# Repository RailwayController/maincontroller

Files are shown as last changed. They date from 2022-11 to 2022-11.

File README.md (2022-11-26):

<!--
SPDX-FileCopyrightText: 2022 Sidings Media <contact@sidingsmedia.com>
SPDX-License-Identifier: CC-BY-SA-4.0
-->

# Railway Controller - Main control board

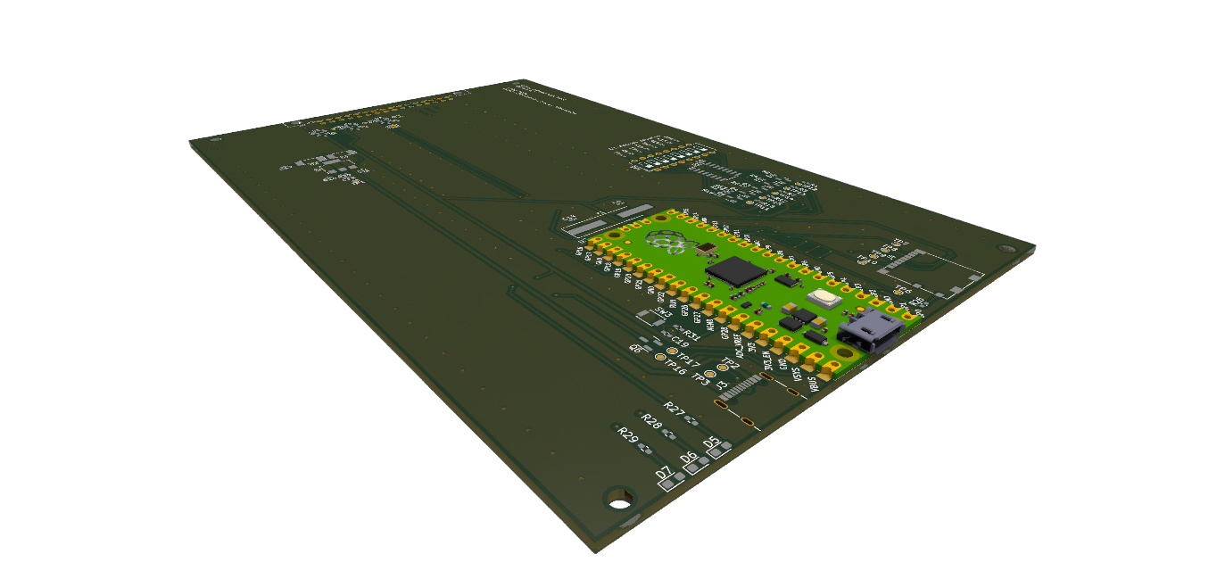
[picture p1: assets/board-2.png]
Render of main control board


The main control board is the central control node of the railway controller
system. The main control board controls all aspects of the system, from handling
user inputs to sending commands to the control nodes.

The board is based upon the RP2040 and can either be fitted with a Raspberry Pi
Pico board or use the RP2040 chip on it's own with all the required supporting
circuitry being implemented on the board it's self. The board is designed to fit
inside a standard 3U eurocard enclosure with a depth of 160mm and a height of
100mm. The rear connector provides connectivity to the backplane to allow
communication between all nodes in the rack as well as to supply power to the
board.

The PCBs have been designed with 2 layers and with SMD components that should be
possible to hand solder with a small tip and some practice. An important note,
the boards have been designed acording to JLCPCB's design constraints, if you
are ordering from a different manufacturer, it is a good idea to make sure that
they support the same or better constraints.

This repository contains designs for the main controller board for
use with the railway controller system. Rendered versions of the schematics, for
example schematics in the PDF format, are included with the releases. Gerber
files are also included with releases. These have been generated to work with
JLCPCB but they should work with most other board manufacturers. 

## Licence
This repo uses the [REUSE](https://reuse.software) standard in order to
communicate the correct licence for the file. For those unfamiliar with
the standard the licence for each file can be found in one of three
places. The licence will either be in a comment block at the top of the
file, in a `.license` file with the same name as the file, or in the
dep5 file located in the `.reuse` directory. If you are unsure of the
licencing terms please contact
[contact@sidingsmedia.com](mailto:contact@sidingsmedia.com?subject=Railway%20Controller%20Licence).
All files committed to this repo must contain valid licencing
information or the pull request can not be accepted.

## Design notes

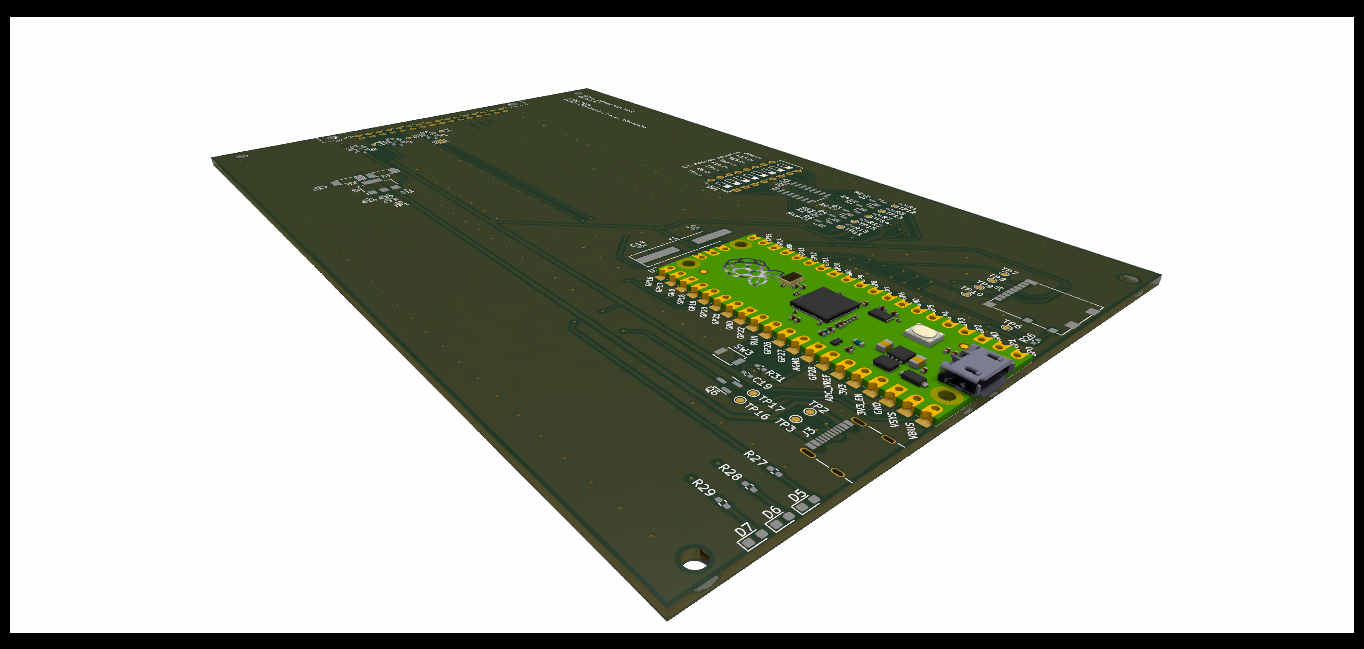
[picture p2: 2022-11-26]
assets/board-1.png

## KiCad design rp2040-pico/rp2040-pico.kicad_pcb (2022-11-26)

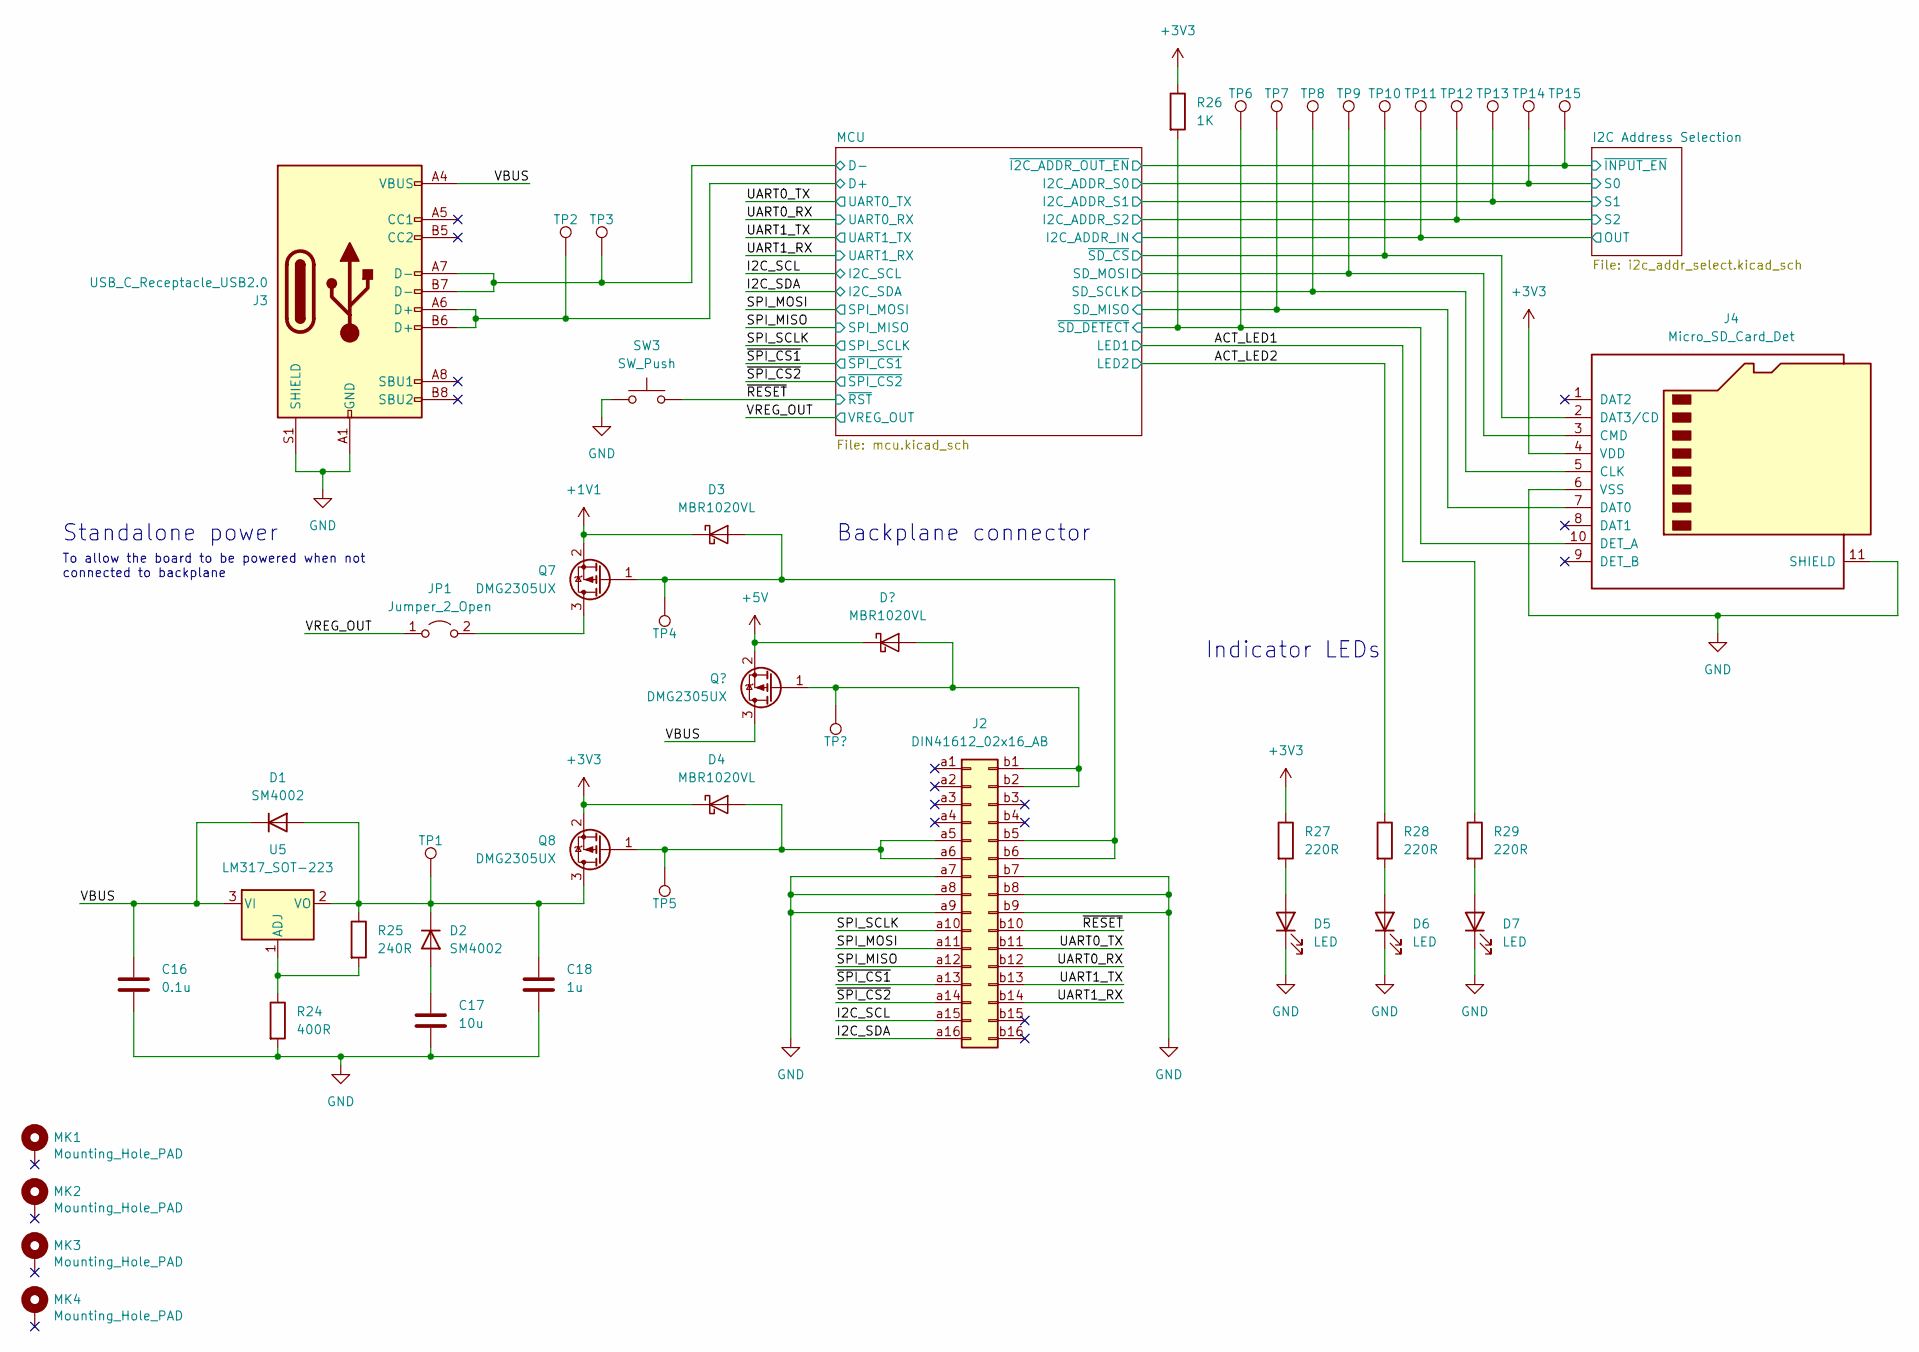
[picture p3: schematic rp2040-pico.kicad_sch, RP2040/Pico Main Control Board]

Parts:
C16: 0.1u; C_0402_1005Metric_Pad0.74x0.62mm_HandSolder
C17: 10u; C_0402_1005Metric_Pad0.74x0.62mm_HandSolder
C18: 1u; C_0402_1005Metric_Pad0.74x0.62mm_HandSolder
D1, D2: SM4002; D_MELF
D3, D4: MBR1020VL; D_SOD-123F
D5, D6, D7: LED; LED_0603_1608Metric_Pad1.05x0.95mm_HandSolder
J2: DIN41612_02x16_AB; DIN41612_B2_2x16_Male_Horizontal_THT
J3: USB_C_Receptacle_USB2.0; USB_C_Receptacle_Palconn_UTC16-G
J4: Micro_SD_Card_Det; microSD_HC_Molex_104031-0811
JP1: Jumper_2_Open; SolderJumper-2_P1.3mm_Open_Pad1.0x1.5mm
MK1, MK2, MK3, MK4: Mounting_Hole_PAD; MountingHole_2.7mm
Q7, Q8: DMG2305UX; SOT-23
R24: 400R; R_0402_1005Metric_Pad0.72x0.64mm_HandSolder
R25: 240R; R_0402_1005Metric_Pad0.72x0.64mm_HandSolder
R26: 1K; R_0402_1005Metric_Pad0.72x0.64mm_HandSolder
R27, R28, R29: 220R; R_0402_1005Metric_Pad0.72x0.64mm_HandSolder
SW3: SW_Push; SW_SPST_B3U-1000P
TP1, TP2, TP3, TP4, TP5, TP6, TP7, TP8, TP9, TP10, TP11, TP12, TP13, TP14, TP15: TestPoint; TestPoint_Pad_D1.0mm
U5: LM317_SOT-223; SOT-223-3_TabPin2

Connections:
+1V1: D3.1 (K), Q7.2 (S); also elsewhere on the board
+3V3: D4.1 (K), J4.4 (VDD), Q8.2 (S), R26.1, R27.1; also elsewhere on the board
/ACT_LED1: R29.1; also elsewhere on the board
/ACT_LED2: R28.1; also elsewhere on the board
/I2C Address Selection/OUT: TP11.1; also elsewhere on the board
/I2C Address Selection/S0: TP14.1; also elsewhere on the board
/I2C Address Selection/S1: TP13.1; also elsewhere on the board
/I2C Address Selection/S2: TP12.1; also elsewhere on the board
/I2C Address Selection/~INPUT_EN: TP15.1; also elsewhere on the board
/I2C_SCL: J2.a15; also elsewhere on the board
/I2C_SDA: J2.a16; also elsewhere on the board
/MCU/D+: J3.A6 (D+), J3.B6 (D+), TP2.1; also elsewhere on the board
/MCU/D-: J3.A7 (D-), J3.B7 (D-), TP3.1; also elsewhere on the board
/MCU/SD_MISO: J4.7 (DAT0), TP7.1; also elsewhere on the board
/MCU/SD_MOSI: J4.3 (CMD), TP9.1; also elsewhere on the board
/MCU/SD_SCLK: J4.5 (CLK), TP8.1; also elsewhere on the board
/MCU/~SD_CS: J4.2 (DAT3/CD), TP10.1; also elsewhere on the board
/MCU/~SD_DETECT: J4.10 (DET_A), R26.2, TP6.1; also elsewhere on the board
/SPI_MISO: J2.a12; also elsewhere on the board
/SPI_MOSI: J2.a11; also elsewhere on the board
/SPI_SCLK: J2.a10; also elsewhere on the board
/UART0_RX: J2.b12; also elsewhere on the board
/UART0_TX: J2.b11; also elsewhere on the board
/UART1_RX: J2.b14; also elsewhere on the board
/UART1_TX: J2.b13; also elsewhere on the board
/VBUS: C16.1, D1.1 (K), J3.A4 (VBUS), J3.A9 (VBUS), J3.B4 (VBUS), J3.B9 (VBUS), U5.3 (VI); also elsewhere on the board
/VREG_OUT: JP1.1 (A); also elsewhere on the board
/~RESET: J2.b10, SW3.2; also elsewhere on the board
/~SPI_CS1: J2.a13; also elsewhere on the board
/~SPI_CS2: J2.a14; also elsewhere on the board
GND: C16.2, C17.2, C18.2, D5.1 (K), D6.1 (K), D7.1 (K), J2.a7, J2.a8, J2.a9, J2.b7, J2.b8, J2.b9, J3.A1 (GND), J3.A12 (GND), J3.B1 (GND), J3.B12 (GND), J3.S1 (SHIELD), J4.6 (VSS), J4.11 (SHIELD), R24.2, SW3.1; also elsewhere on the board
unnamed: C17.1, D2.2 (A)
unnamed: C18.1, D1.2 (A), D2.1 (K), Q8.3 (D), R25.1, TP1.1, U5.2 (VO)
unnamed: D3.2 (A), J2.b5, J2.b6, Q7.1 (G), TP4.1
unnamed: D4.2 (A), J2.a5, J2.a6, Q8.1 (G), TP5.1
unnamed: D5.2 (A), R27.2
unnamed: D6.2 (A), R28.2
unnamed: D7.2 (A), R29.2
unnamed 51: J2.b1, J2.b2; also elsewhere on the board
unnamed: JP1.2 (B), Q7.3 (D)
unnamed: R24.1, R25.2, U5.1 (ADJ)

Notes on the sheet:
To allow the board to be powered when not connected to backplane
Backplane connector
Standalone power
Indicator LEDs

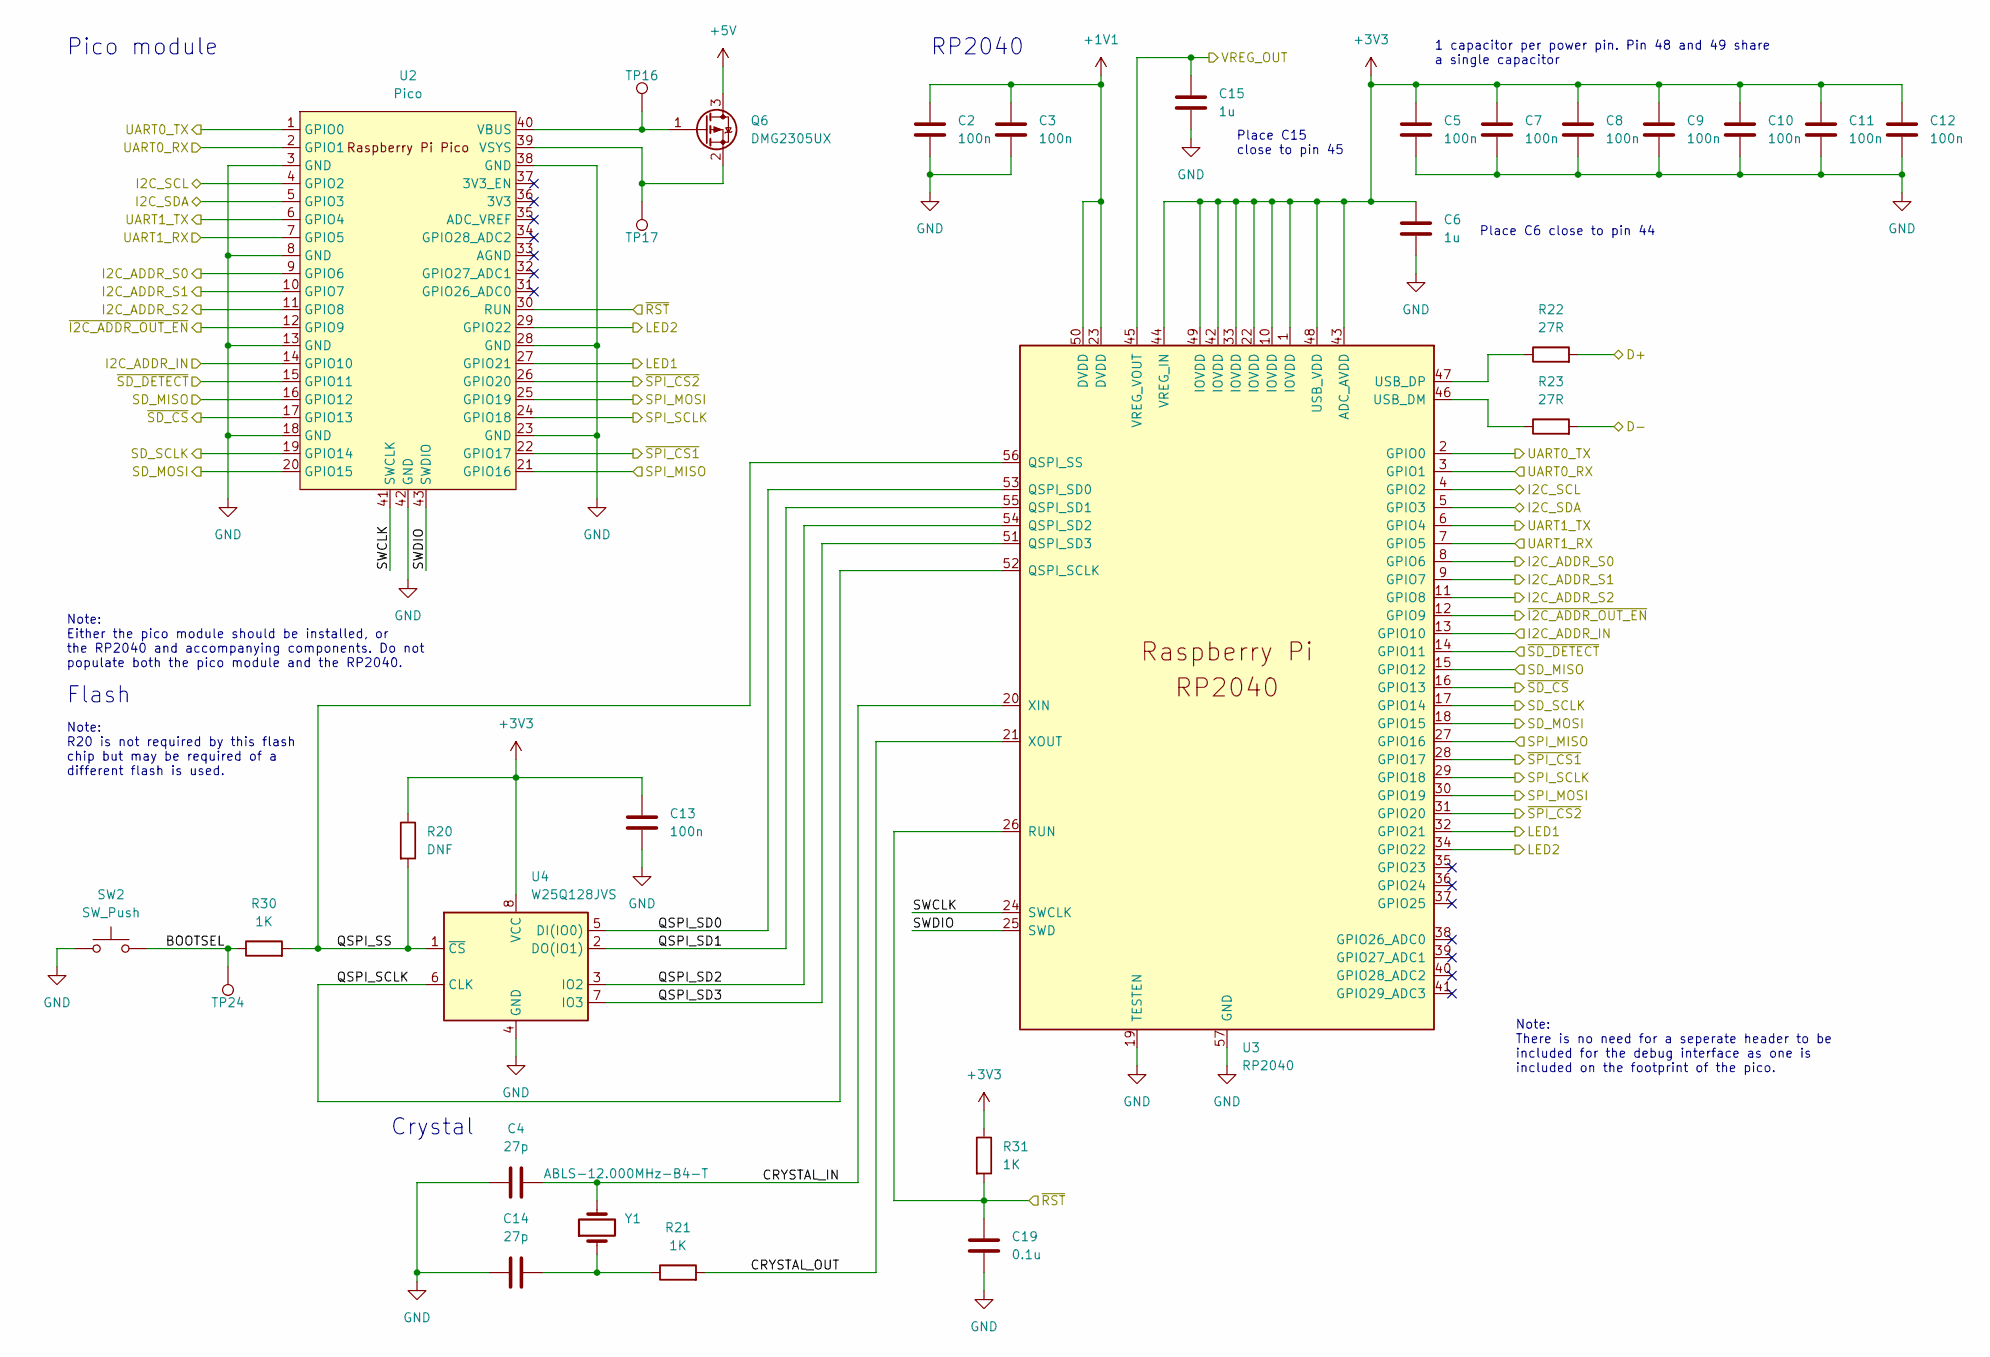
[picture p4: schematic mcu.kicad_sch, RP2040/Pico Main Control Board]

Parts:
C2, C3, C5, C7, C8, C9, C10, C11, C12, C13: 100n; C_0402_1005Metric_Pad0.74x0.62mm_HandSolder
C4, C14: 27p; C_0402_1005Metric_Pad0.74x0.62mm_HandSolder
C6, C15: 1u; C_0402_1005Metric_Pad0.74x0.62mm_HandSolder
C19: 0.1u; C_0402_1005Metric_Pad0.74x0.62mm_HandSolder
Q6: DMG2305UX; SOT-23
R20: DNF; R_0402_1005Metric_Pad0.72x0.64mm_HandSolder
R21, R30, R31: 1K; R_0402_1005Metric_Pad0.72x0.64mm_HandSolder
R22, R23: 27R; R_0402_1005Metric_Pad0.72x0.64mm_HandSolder
SW2: SW_Push; SW_SPST_B3U-1000P
TP16, TP17, TP24: TestPoint; TestPoint_Pad_D1.0mm
U2: Pico; RPi_Pico_SMD_TH
U3: RP2040; RP2040-QFN-56
U4: W25Q128JVS; SOIC-8_5.23x5.23mm_P1.27mm
Y1: ABLS-12.000MHz-B4-T; Crystal_SMD_HC49-SD_HandSoldering

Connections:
+1V1: C2.1, C3.1, U3.23 (DVDD), U3.50 (DVDD); also elsewhere on the board
+3V3: C5.1, C6.1, C7.1, C8.1, C9.1, C10.1, C11.1, C12.1, C13.1, R20.1, R31.1, U3.1 (IOVDD), U3.10 (IOVDD), U3.22 (IOVDD), U3.33 (IOVDD), U3.42 (IOVDD), U3.43 (ADC_AVDD), U3.44 (VREG_IN), U3.48 (USB_VDD), U3.49 (IOVDD), U4.8 (VCC); also elsewhere on the board
+5V: Q6.3 (D); also elsewhere on the board
/ACT_LED1: U2.27 (GPIO21), U3.32 (GPIO21); also elsewhere on the board
/ACT_LED2: U2.29 (GPIO22), U3.34 (GPIO22); also elsewhere on the board
/I2C Address Selection/OUT: U2.14 (GPIO10), U3.13 (GPIO10); also elsewhere on the board
/I2C Address Selection/S0: U2.9 (GPIO6), U3.8 (GPIO6); also elsewhere on the board
/I2C Address Selection/S1: U2.10 (GPIO7), U3.9 (GPIO7); also elsewhere on the board
/I2C Address Selection/S2: U2.11 (GPIO8), U3.11 (GPIO8); also elsewhere on the board
/I2C Address Selection/~INPUT_EN: U2.12 (GPIO9), U3.12 (GPIO9); also elsewhere on the board
/I2C_SCL: U2.4 (GPIO2), U3.4 (GPIO2); also elsewhere on the board
/I2C_SDA: U2.5 (GPIO3), U3.5 (GPIO3); also elsewhere on the board
/MCU/BOOTSEL: R30.1, SW2.2, TP24.1
/MCU/CRYSTAL_IN: C4.2, U3.20 (XIN), Y1.2
/MCU/CRYSTAL_OUT: R21.2, U3.21 (XOUT)
/MCU/D+: R22.2; also elsewhere on the board
/MCU/D-: R23.2; also elsewhere on the board
/MCU/QSPI_SCLK: U3.52 (QSPI_SCLK), U4.6 (CLK)
/MCU/QSPI_SD0: U3.53 (QSPI_SD0), U4.5 (DI(IO0))
/MCU/QSPI_SD1: U3.55 (QSPI_SD1), U4.2 (DO(IO1))
/MCU/QSPI_SD2: U3.54 (QSPI_SD2), U4.3 (IO2)
/MCU/QSPI_SD3: U3.51 (QSPI_SD3), U4.7 (IO3)
/MCU/QSPI_SS: R20.2, R30.2, U3.56 (QSPI_SS), U4.1 (~CS)
/MCU/SD_MISO: U2.16 (GPIO12), U3.15 (GPIO12); also elsewhere on the board
/MCU/SD_MOSI: U2.20 (GPIO15), U3.18 (GPIO15); also elsewhere on the board
/MCU/SD_SCLK: U2.19 (GPIO14), U3.17 (GPIO14); also elsewhere on the board
/MCU/SWCLK: U2.41 (SWCLK), U3.24 (SWCLK)
/MCU/SWDIO: U2.43 (SWDIO), U3.25 (SWD)
/MCU/~SD_CS: U2.17 (GPIO13), U3.16 (GPIO13); also elsewhere on the board
/MCU/~SD_DETECT: U2.15 (GPIO11), U3.14 (GPIO11); also elsewhere on the board
/SPI_MISO: U2.21 (GPIO16), U3.27 (GPIO16); also elsewhere on the board
/SPI_MOSI: U2.25 (GPIO19), U3.30 (GPIO19); also elsewhere on the board
/SPI_SCLK: U2.24 (GPIO18), U3.29 (GPIO18); also elsewhere on the board
/UART0_RX: U2.2 (GPIO1), U3.3 (GPIO1); also elsewhere on the board
/UART0_TX: U2.1 (GPIO0), U3.2 (GPIO0); also elsewhere on the board
/UART1_RX: U2.7 (GPIO5), U3.7 (GPIO5); also elsewhere on the board
/UART1_TX: U2.6 (GPIO4), U3.6 (GPIO4); also elsewhere on the board
/VREG_OUT: C15.1, U3.45 (VREG_VOUT); also elsewhere on the board
/~RESET: C19.1, R31.2, U2.30 (RUN), U3.26 (RUN); also elsewhere on the board
/~SPI_CS1: U2.22 (GPIO17), U3.28 (GPIO17); also elsewhere on the board
/~SPI_CS2: U2.26 (GPIO20), U3.31 (GPIO20); also elsewhere on the board
GND: C2.2, C3.2, C4.1, C5.2, C6.2, C7.2, C8.2, C9.2, C10.2, C11.2, C12.2, C13.2, C14.1, C15.2, C19.2, SW2.1, U2.3 (GND), U2.8 (GND), U2.13 (GND), U2.18 (GND), U2.23 (GND), U2.28 (GND), U2.38 (GND), U2.42 (GND), U3.19 (TESTEN), U3.57 (GND), U4.4 (GND); also elsewhere on the board
unnamed: C14.2, R21.1, Y1.1
unnamed: Q6.1 (G), TP16.1, U2.40 (VBUS)
unnamed: Q6.2 (S), TP17.1, U2.39 (VSYS)
unnamed: R22.1, U3.47 (USB_DP)
unnamed: R23.1, U3.46 (USB_DM)

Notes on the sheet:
Flash
Pico module
Place C15 close to pin 45
1 capacitor per power pin. Pin 48 and 49 share a single capacitor
Note: Either the pico module should be installed, or the RP2040 and accompanying components. Do not populate both the pico module and the RP2040.
Note: There is no need for a seperate header to be included for the debug interface as one is included on the footprint of the pico.
Place C6 close to pin 44
Crystal
RP2040
Note: R20 is not required by this flash chip but may be required of a different flash is used.

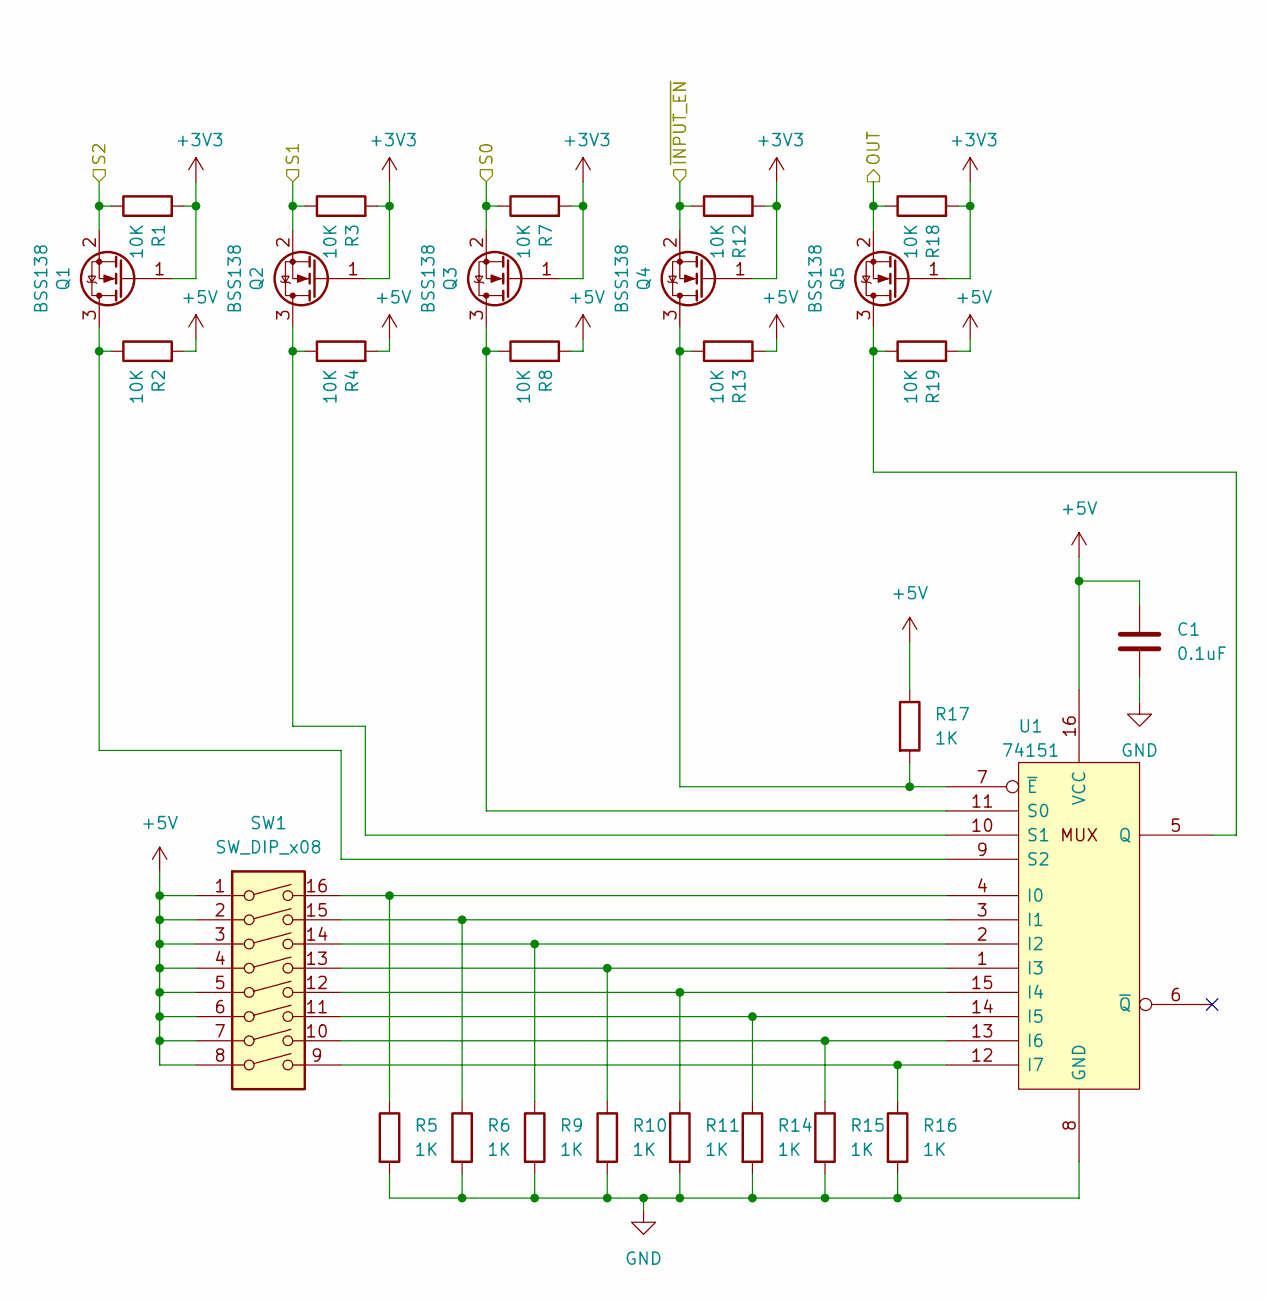
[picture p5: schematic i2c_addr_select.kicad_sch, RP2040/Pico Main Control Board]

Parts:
C1: 0.1uF; C_0402_1005Metric_Pad0.74x0.62mm_HandSolder
Q1, Q2, Q3, Q4, Q5: BSS138; SOT-23
R1, R2, R3, R4, R7, R8, R12, R13, R18, R19: 10K; R_0402_1005Metric_Pad0.72x0.64mm_HandSolder
R5, R6, R9, R10, R11, R14, R15, R16, R17: 1K; R_0402_1005Metric_Pad0.72x0.64mm_HandSolder
SW1: SW_DIP_x08; SW_DIP_SPSTx08_Slide_6.7x21.88mm_W7.62mm_P2.54mm_LowProfile
U1: 74151; SOIC-16_3.9x9.9mm_P1.27mm

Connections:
+3V3: Q1.1 (G), Q2.1 (G), Q3.1 (G), Q4.1 (G), Q5.1 (G), R1.2, R3.2, R7.2, R12.2, R18.2; also elsewhere on the board
+5V: C1.1, R2.2, R4.2, R8.2, R13.2, R17.1, R19.2, SW1.1, SW1.2, SW1.3, SW1.4, SW1.5, SW1.6, SW1.7, SW1.8, U1.16 (VCC); also elsewhere on the board
/I2C Address Selection/OUT: Q5.2 (S), R18.1; also elsewhere on the board
/I2C Address Selection/S0: Q3.2 (S), R7.1; also elsewhere on the board
/I2C Address Selection/S1: Q2.2 (S), R3.1; also elsewhere on the board
/I2C Address Selection/S2: Q1.2 (S), R1.1; also elsewhere on the board
/I2C Address Selection/~INPUT_EN: Q4.2 (S), R12.1; also elsewhere on the board
GND: C1.2, R5.2, R6.2, R9.2, R10.2, R11.2, R14.2, R15.2, R16.2, U1.8 (GND); also elsewhere on the board
unnamed: Q1.3 (D), R2.1, U1.9 (S2)
unnamed: Q2.3 (D), R4.1, U1.10 (S1)
unnamed: Q3.3 (D), R8.1, U1.11 (S0)
unnamed: Q4.3 (D), R13.1, R17.2, U1.7 (~E)
unnamed: Q5.3 (D), R19.1, U1.5 (Q)
unnamed: R5.1, SW1.16, U1.4 (I0)
unnamed: R6.1, SW1.15, U1.3 (I1)
unnamed: R9.1, SW1.14, U1.2 (I2)
unnamed: R10.1, SW1.13, U1.1 (I3)
unnamed: R11.1, SW1.12, U1.15 (I4)
unnamed: R14.1, SW1.11, U1.14 (I5)
unnamed: R15.1, SW1.10, U1.13 (I6)
unnamed: R16.1, SW1.9, U1.12 (I7)

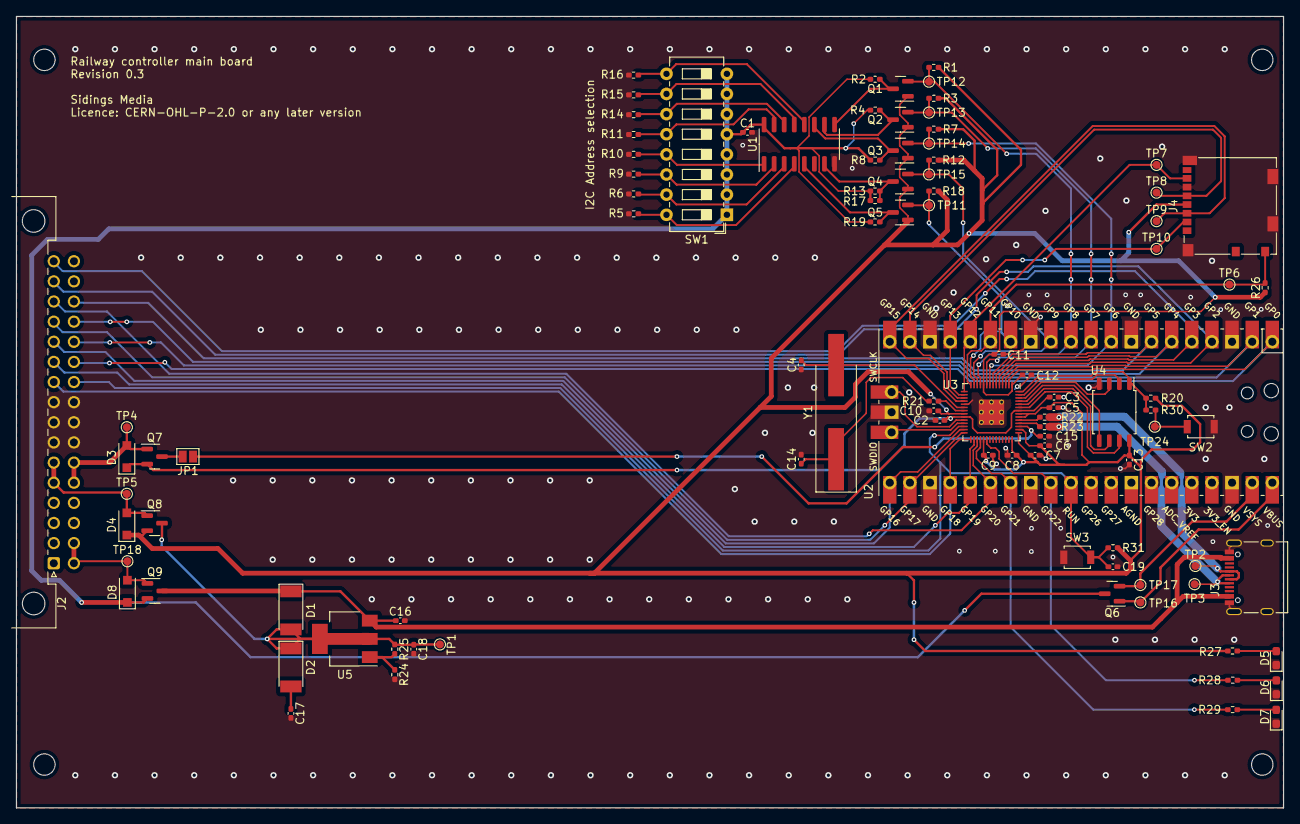
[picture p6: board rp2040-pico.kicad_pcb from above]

Board: 2 copper layers, 159.9 x 99.9 mm, 103 parts (0 on the bottom side), 71 nets.

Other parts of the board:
D8: MBR1020VL; D_SOD-123F
Q9: DMG2305UX; SOT-23
TP18: TestPoint; TestPoint_Pad_D1.0mm

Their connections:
+5V: D8.1 (K), Q9.2 (S); also elsewhere on the board
/VBUS: Q9.3 (D); also elsewhere on the board
unnamed 51: D8.2 (A), Q9.1 (G), TP18.1; also elsewhere on the board

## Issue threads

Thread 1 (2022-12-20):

Remove backplane reset

Computroniks, 2022-12-20:
The reset pin on the backplane connector has been removed. As such it should be disconnected. See RailwayController/speedcontroller#2 and https://github.com/RailwayController/speedcontroller/commit/2c5319723838c0ab59ae9542d99c536fc1f70295

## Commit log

2022-11-18 Initialized KiCad Project
    [rp2040-pico.kicad_pcb, rp2040-pico.kicad_sch]
2022-11-18 Fixed reuse + updated schematic template
    Reuse compatability has been fixed by updating the dep5 file.
    Also updated template for schematic and filled in schematic info
    fields.
    [rp2040-pico.kicad_sch]
2022-11-18 Initial board design
    The initial design for the Rasbperry Pi Pico based board.
    [rp2040-pico.kicad_sch]
2022-11-20 Updated RP2040 schematic to include RP2040 + Pico
    The schematic has been updated to now include the option to either use a
    raspberry pi pico module, or to use an RP2040.
    [i2c_addr_select.kicad_sch, mcu.kicad_sch, rp2040-pico.kicad_sch]
2022-11-20 Added stat LEDs, BOOTSEL and reset button, SD card
    3 LEDs have been added. One for indicating power and two for indicating
    activity. Both activity LEDs are currently connected to the Pico/RP2040.
    Buttons for boot selection and chip reset have been added to allow for
    loading of firmware over USB. Support for a micro SD has also been
    added. The card communicates with the Pico/RP2040 via the MCUs second
    SPI interface and will store config files.
    [i2c_addr_select.kicad_sch, mcu.kicad_sch, rp2040-pico.kicad_sch]
2022-11-20 Changed LM317 decoupling caps to non polarized
    There is no need for C16, C17 or C18 to be polarized capacitors. As
    such, they have been changed to be non polarized.
    [rp2040-pico.kicad_sch]
2022-11-20 Assigned value to C19
    [mcu.kicad_sch, rp2040-pico.kicad_sch]
2022-11-20 Added device footprints
    [i2c_addr_select.kicad_sch, mcu.kicad_sch, rp2040-pico.kicad_sch]
2022-11-20 Updated schematic and started PCB development
    Test points have been removed from the schematic where they were found
    to be unnecessary or would make efficient placement of components
    impossible. Most notable the test points connected to the flash chip.
    These are not required as one can just probe the pins of the flash chip
    with ease.
    Some nets have also been labeled to assist in PCB development.
    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
    [mcu.kicad_sch, rp2040-pico.kicad_pcb, rp2040-pico.kicad_sch]
2022-11-26 Added rev 0.3 PCB + minor alterations to schematic
    The PCB design work has been completed for rev 0.3 of the board. Some
    minor changes to the schematic were made as issues were encountered
    during board design. The most notable being the removal of unneccessary
    test points and the addition of another P-channel mosfet to allow the 5V
    rail to have two seperate power supplies.
    [rp2040-pico.kicad_pcb, rp2040-pico.kicad_sch]
2022-11-26 Rendered schematic for rev 0.3
2022-11-26 Added interactive BOM for rev 0.3
2022-11-26 Switched pour mode to full connections
    Previously the fill mode was set to use thermal reliefs, however this
    led to some vias not being properly connected.
    [rp2040-pico.kicad_pcb]
2022-11-26 Some minor changes and increment version number
    [i2c_addr_select.kicad_sch, mcu.kicad_sch, rp2040-pico.kicad_sch]
2022-11-27 Minor changes to UUIDs
    [mcu.kicad_sch, rp2040-pico.kicad_sch]

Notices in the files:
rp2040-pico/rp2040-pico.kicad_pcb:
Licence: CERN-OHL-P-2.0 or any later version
